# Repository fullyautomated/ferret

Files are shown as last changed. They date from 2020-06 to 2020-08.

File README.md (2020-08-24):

# Free-wheeling Ferret

USB-C Programmable Power Supply Source and Sink.

Back side optimized for JLCSMT, front for hand placing.
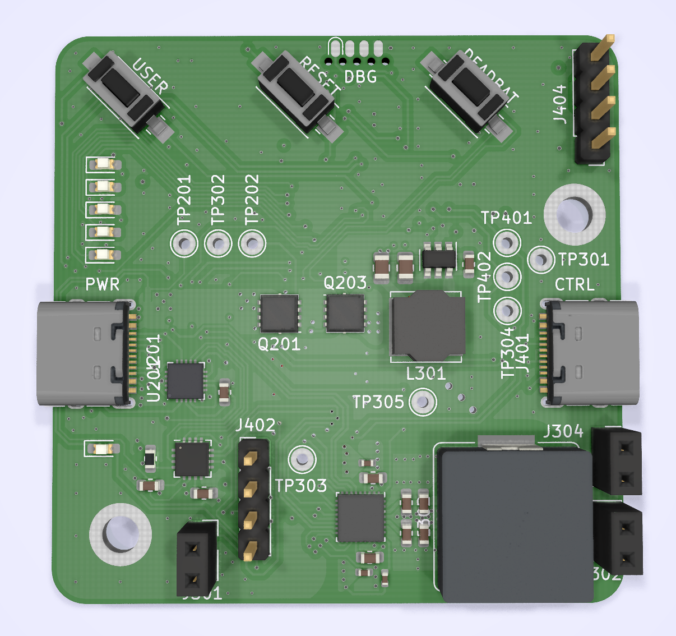
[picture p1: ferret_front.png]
Front

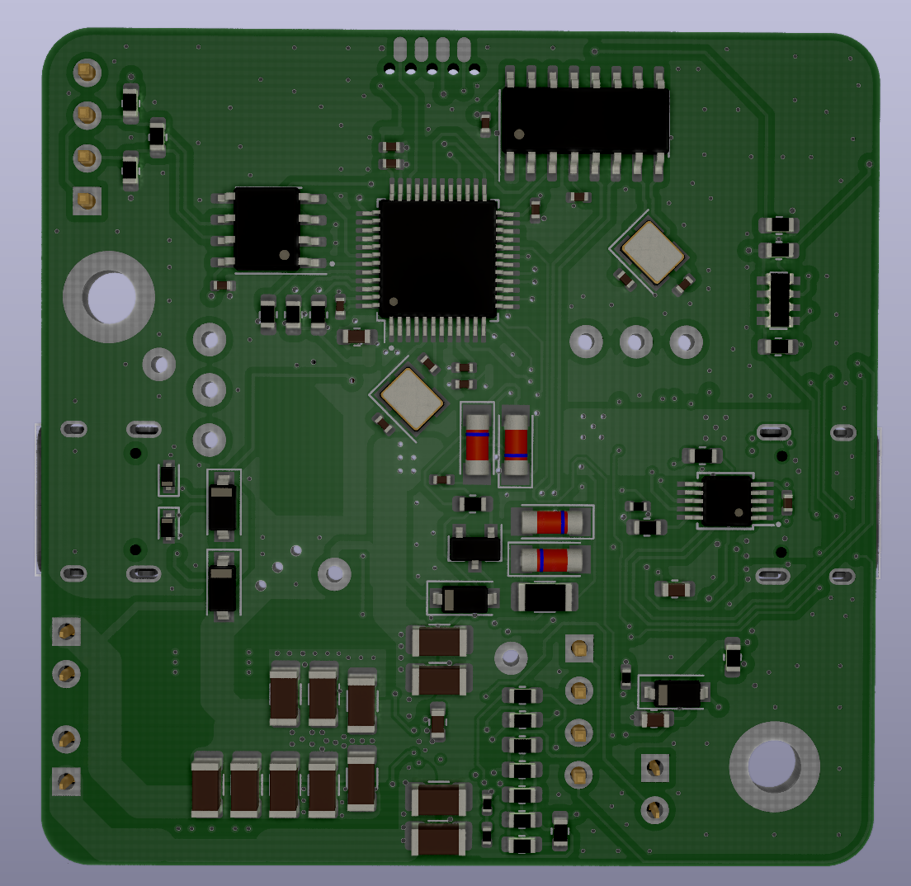
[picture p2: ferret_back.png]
Back


## Scattered Notes
Rough idea: Use the existing 10 boards to iron out firmware and get a good feel on the workings of USB-C PD. Then respin the boards, split the management functionality onto a separate board and make the Ferrets stackable.  

Ecosystem Idea:
 - Stackable Ferrets; you can have any\* amount of type C ports you can possibly need. Ferrets can have individual legacy electricity I/O, or can be tied to a single common bus. With the 
 - Configuration Board (top position only) you can monitor power flow and change port settings (source/sink, current and voltage) - this has a management interface (USB UART) and maybe Bluetooth/Wifi with an ESP32. Energy is stored in the
 - Battery Board; 4s BMS which can be attached to the bottom of a Ferret Stack. If you want to tie your Ferrets to a DC network with voltages usupported by the Ferret (so above 24V), you can just take an
 - Autobus; a 4-switch buck-boost converter with up to 60-V capability and hundreds of watts of power. This can easily interface with solar panels of larger size, 12-V lead-acid batteries, or 48-V grids. For cheaper, lower power connectivity you can use any additional stackable
 - Boost or Buck converter boards.

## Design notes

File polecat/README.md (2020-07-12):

# Pondering Polecat

USB-C PD PPS 8A supply breakout board. Just the initial schematic doodle for now.

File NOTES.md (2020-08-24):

# Notes about future revisions

## Alternative/interesting ICs

### ACT2861

The [ACT2861](https://www.qorvo.com/products/p/ACT2861) ([datasheet](https://www.qorvo.com/products/d/da006757)) is a 5S charger IC with OTG capabilities. Comparable with the TI chip, but not quite as good of a feature-set.

### ACT4752

The [ACT4752](https://www.qorvo.com/products/p/ACT4752) ([datasheet](https://www.qorvo.com/products/d/da007821)) is a cheaper alternative for source only applications but can be supplied with up to 40V and outputs up to 4A, with 256 step (15,625mA) current limit.

This would be perfect for output only boards, as it's also a lot cheaper (2.83EUR currently) and has integrated MOSFETs too.

### ISL95338

The [ISL95338](https://www.renesas.com/us/en/products/power-management/battery-management/multiple-cell-battery-chargers/device/ISL95338.html) ([datasheet](https://www.renesas.com/en-us/www/doc/datasheet/isl95338.pdf)) needs external MOSFETs and is *very* expensive. Not really interesting.

### LT8491

[LT8491](https://www.analog.com/en/products/lt8491.html) is just here for completeness sake. Up to 80V input, but ridicously expensive.

### TPS55288

The [TPS55288](https://www.ti.com/product/TPS55288) ([datasheet](https://www.ti.com/lit/ds/symlink/tps55288.pdf)) can do up to 16A out, but only up to 21.26V.
Small qty pricing is currently 4.4USD.

### BQ25713

The [BQ25713](https://www.ti.com/product/BQ25713) ([datasheet](https://www.ti.com/lit/ds/symlink/bq25713.pdf)) can only provide up to 20.8V but up to 8A and only costs 2.576USD for qty 1. Needs external MOSFETs though for better or worse.

See [polecat](polecat/) for schematic.

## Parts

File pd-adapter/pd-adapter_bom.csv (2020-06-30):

Designator | Comment | Footprint | Part Number
C3 C9 | 100nF | 0603 | C14663
C1 C5 C10 C11 C12 C13 C14 | 100nF/50V | 0603 | C14663
C2 | 10uF | 1206 | C13585
C6 | 10uF | 0603 | C19702
C4 C7 C15 | 10uF/10V | 0603 | C19702
C8 | 56pF/50V | 0603 | C39148
D5 | 24V | SOD-323 | C22619
D3 D4 | 3.3V | SOD-523 | C136161
D1 D2 D6 D7 | 5V | SOD-523 | C266462
D9 | Blue/2.8V | LED_0603 | C72041
D10 | Green/3.3V | LED_0603 | C72043
D8 | Red/2V | LED_0603 | C2286
D11 | White/2.9V | LED_0603 | C2290
D12 | Yellow/2.9V | LED_0603 | C72038
L1 | 10uH | 1210 | C86069
R13 | 10 | 0603 | C22859
R5 | 100k | 0603 | C25803
R8 | 10k | 0603 | C25804
R11 R15 | 130 | 0603 | C23185
R6 | 22k | 0603 | C31850
R1 R2 R3 R7 R9 R10 | 4.7k | 0603 | C23162
R12 R14 | 47 | 0603 | C23182
R4 | 49.9 | 0603 | C23185
U1 | FUSB302BMPX | MLP-14_EP_2.5x2.5x0.5P | C132291
U3 | STM32F072C8Tx | LQFP-48_7.0x7.0x0.5P | C80488
U2 | TPS54202DDC | SOT-23-6L | C191884

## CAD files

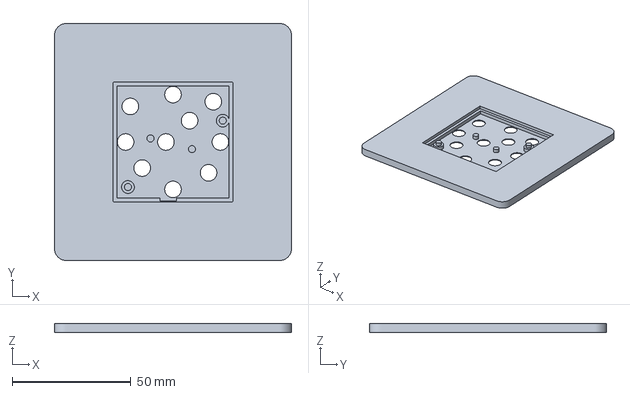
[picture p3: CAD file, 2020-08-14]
jig.3mf
100.0 x 100.0 x 4.00 mm

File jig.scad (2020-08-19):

totalThickness = 3.6;
pcbThickness = 1.65;

holeD = 3.0;
holeShrouD = 5.4;

gap = 0.12;
pcb = [50,50,pcbThickness];

pcbShroud = 1.4;

base = [110, 130, 0.4];

stencilOffset = [0,20,0];
cornerRadius = 5;

holes = [[6,6], [46, 34]];
supportPegs = [[15.5, 26.5], [33, 22]];
supportPegD = 3;

module supports() {
    supportPegH = base.z + totalThickness;
    supportH = supportPegH - pcbThickness;
    
    translate([pcb.x/-2, pcb.y/-2, 0]) {
        for(v=holes)
            translate(v) {
                cylinder(d=holeD, h=supportPegH);
                cylinder(d=holeShrouD, h=supportH);
            }
            
        for(v=supportPegs)
            translate(v)
                cylinder(d=supportPegD, h=supportH); 
        }
}

function getCorners(dim, rr) = (
        [[rr,rr],
        [dim.x - rr, rr],
        [dim.x - rr, dim.y - rr],
        [rr, dim.y - rr]]);

module roundedCube(dim, rr, center=false) {
    translate(center?(-0.5*dim):[0,0,0])
        linear_extrude(dim.z)
            hull()
                for(vector = getCorners(dim, rr))
                    translate(vector)
                        circle(rr);
}

module roundedSquare(dim, rr, center=false) {
        translate(center?(-0.5*[dim.x,dim.y]):[0,0,0])
            hull()
                for(vector = getCorners(dim, rr))
                    translate(vector)
                        circle(rr);
}

module main() {
    totalZ = base.z + totalThickness;
    insides = pcb - pcbShroud*[2,2,0] + [0,0,totalThickness];
    difference() {
        union() {
            // main part +
            translate(stencilOffset)
                linear_extrude(totalZ)
                    roundedSquare([base.x, base.y], cornerRadius, center=true);
        }
        union() {
            // pcb -
            translate([0,0,totalZ-pcb.z])
                linear_extrude(totalZ)
                    offset(r=2*gap)
                        square([pcb.x, pcb.y], center=true);
            
            // clearance for underside 
            // components -
            translate([0,0,base.z])
                linear_extrude(insides.z)
                    square([insides.x, insides.y], center=true);
            
            // additional clearance -
            translate([pcb.x/-2, pcb.y/-2,base.z])
                translate([27, 1.2])
                    linear_extrude(totalZ)
                        square([9,2], center=true);
            
            // eject holes -
            eh = [[25,5], [25,45], [5,25], [45,25], [22, 25], [40, 12], [7, 40], [42, 42], [32,34], [12,14]];
            translate([pcb.x/-2, pcb.y/-2, -1])
            for(v=eh)
                translate(v)
                    cylinder(d=7, h=base.z+2);
        }
    }
    supports();
}

$fn = 64;
main();

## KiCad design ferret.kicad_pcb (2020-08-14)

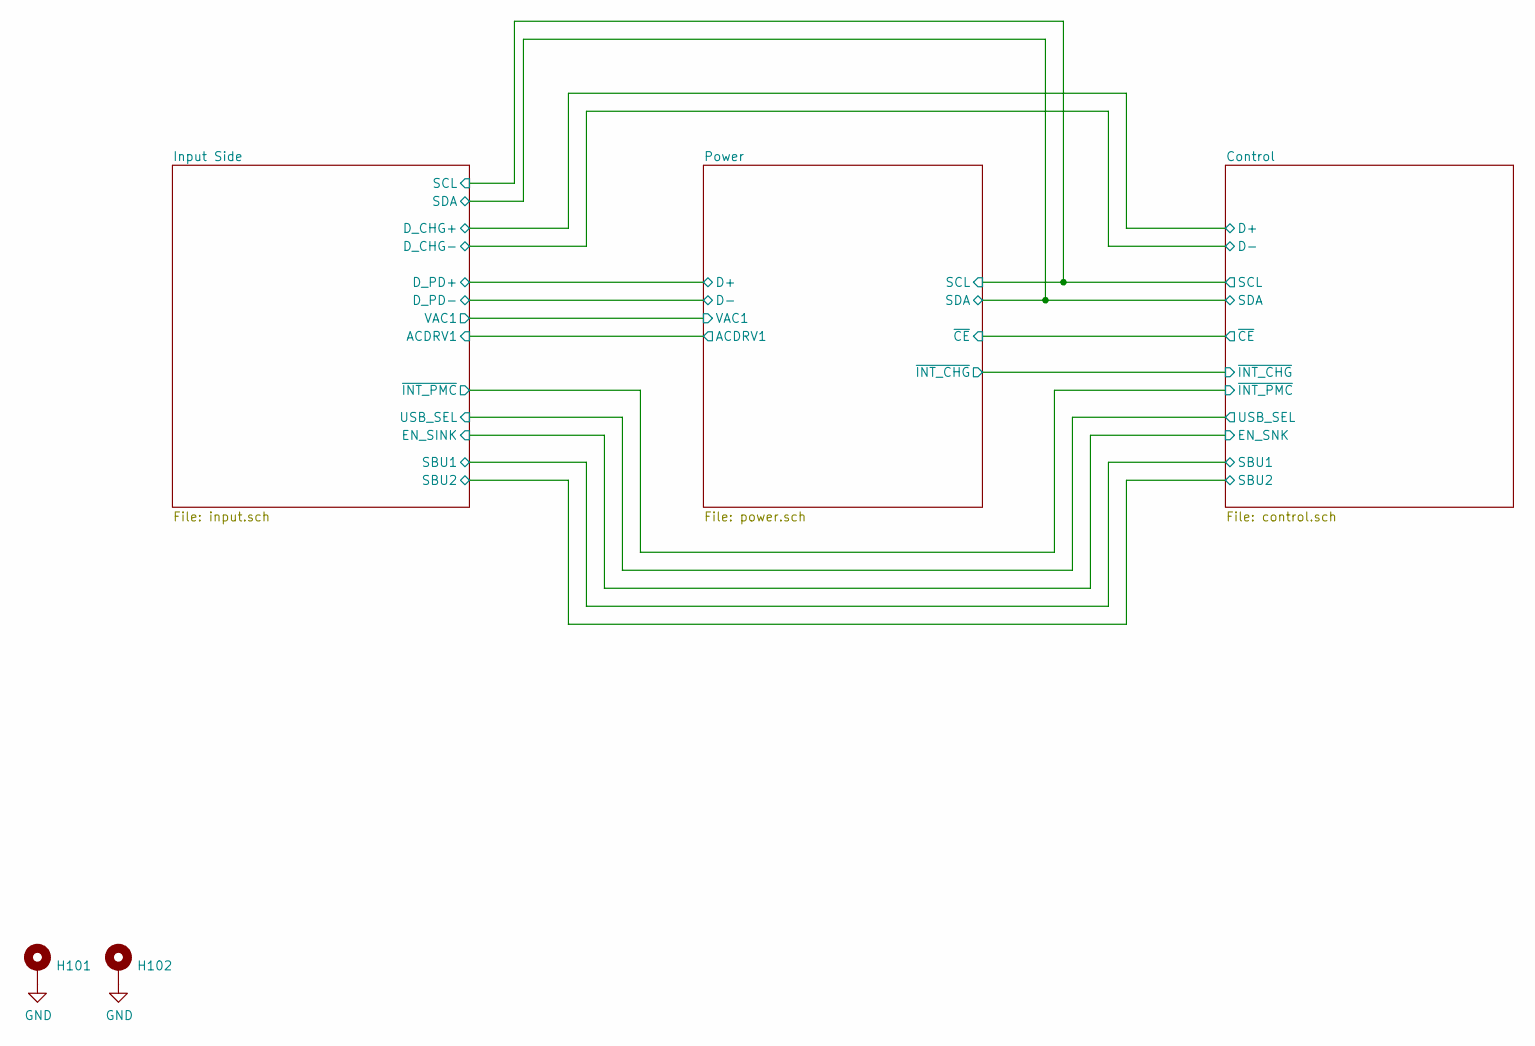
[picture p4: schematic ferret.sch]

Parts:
H101, H102: MountingHole_Pad; MountingHole_3.2mm_M3_ISO14580_Pad; MPN DNP

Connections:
GND: H101.1, H102.1; also elsewhere on the board

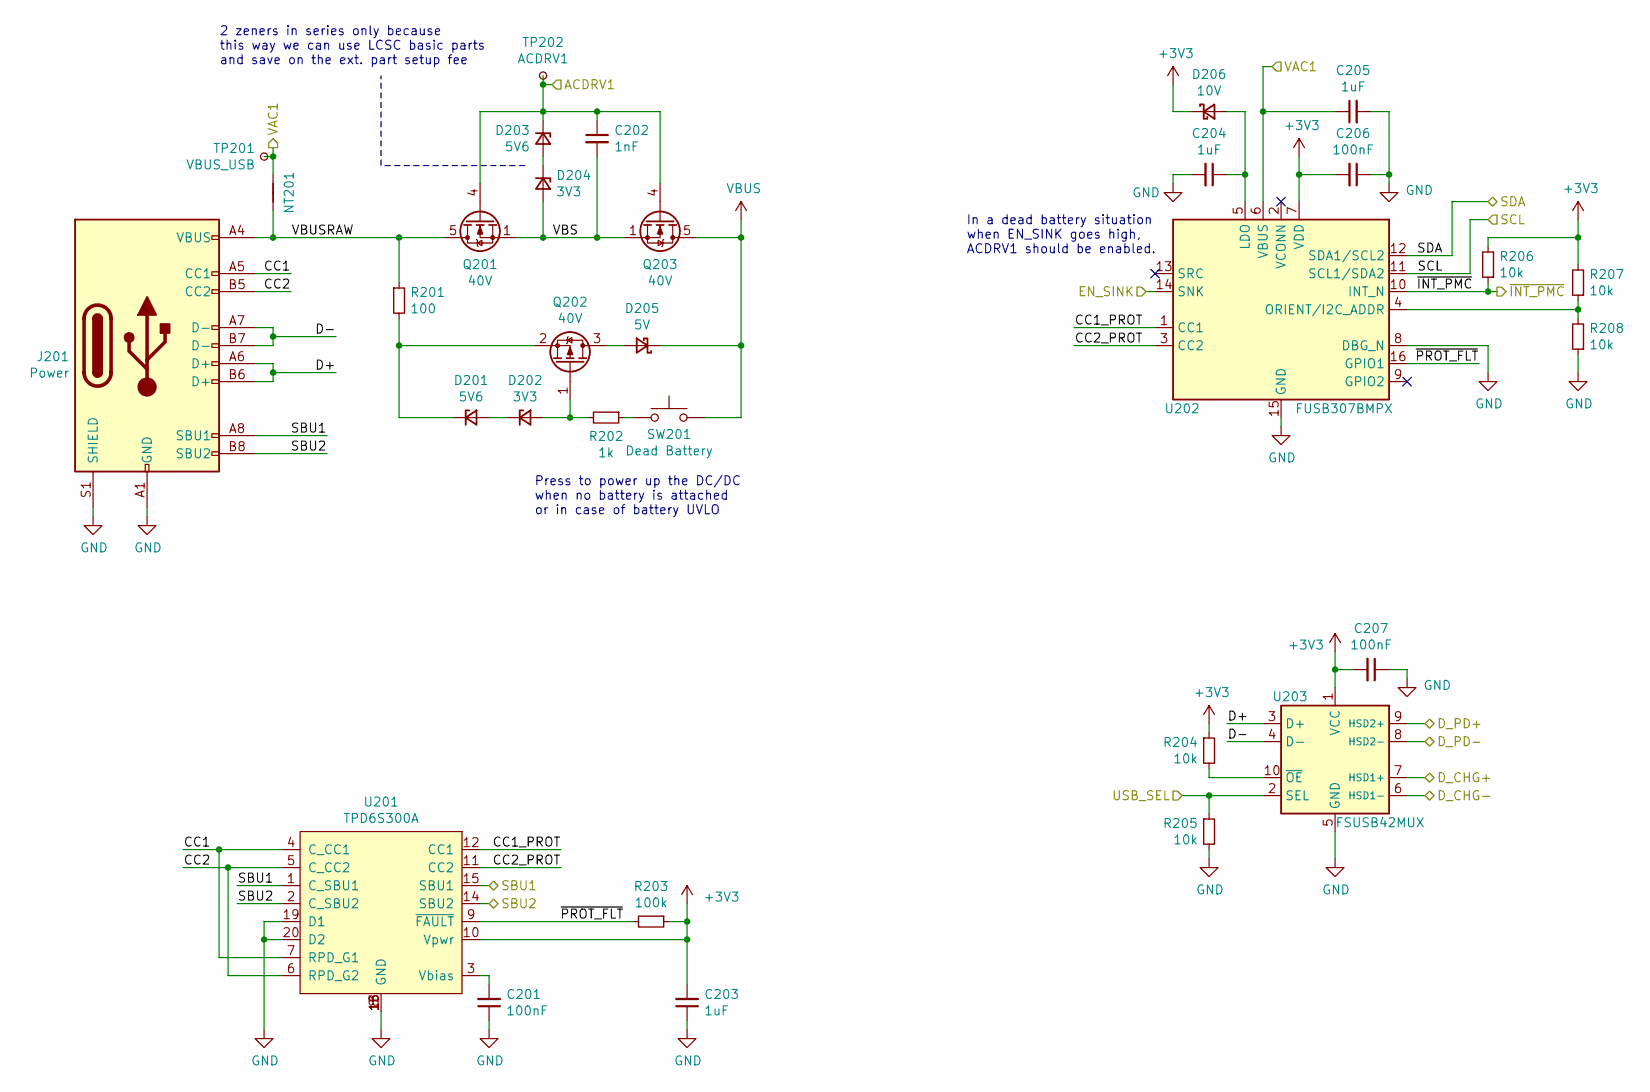
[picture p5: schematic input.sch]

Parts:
C201, C206: 100nF; C_0603_1608Metric; MPN CC0603KRX7R9BB104; JLC 0603
C202: 1nF; C_0402_1005Metric; JLC 0402
C203: 1uF; C_0603_1608Metric; MPN CL10A105KB8NNNC; LCSC C15849
C204: 1uF; C_0603_1608Metric
C205: 1uF; C_0603_1608Metric; LCSC C15849
C207: 100nF; C_0402_1005Metric; JLC 0402
D201, D203: 5V6; D_MiniMELF; MPN ZMM5V6; JLC LL-34
D202, D204: 3V3; D_MiniMELF; MPN ZMM3V3; JLC LL-34
D205: 5V; D_SOD-123; MPN B5819W; JLC SOD-123
D206: 10V; D_SOD-123; MPN B5819W; LCSC C8598
J201: Power; USB_C_Receptacle_XKB_U262-16XN-4BVC11
NT201: UwU; NetTie-2_SMD_Pad0.5mm; MPN DNP
Q201, Q203: 40V; Vishay_PowerPAK_1212-8_Single; MPN SiSS10ADN
Q202: 40V; SOT-23; MPN AO3401; JLC SOT-23-3L
R201: 100; R_1206_3216Metric; MPN 1206W4F1000T5E; JLC 1206
R202: 1k; R_0603_1608Metric; MPN 0603WAF1001T5E; JLC 0603
R203: 100k; R_0402_1005Metric; JLC 0402
R204, R205: 10k; R_0603_1608Metric; JLC 0603
R206: 10k; R_0402_1005Metric; JLC 0402
R207, R208: 10k; R_0603_1608Metric; MPN DNP; JLC 0603
SW201: Dead Battery; SW_SPST_PTS636_G
TP201: VBUS_USB; TestPoint_THTPad_D2.0mm_Drill1.0mm
TP202: ACDRV1; TestPoint_THTPad_D2.0mm_Drill1.0mm
U201: TPD6S300A; QFN-20-1EP_3x3mm_P0.4mm_EP1.65x1.65mm; MPN TPD6S300ARUKR
U202: FUSB307BMPX; WQFN-16-1EP_3x3mm_P0.5mm_EP1.75x1.75mm
U203: FSUSB42MUX; MSOP-10_3x3mm_P0.5mm; MPN FSUSB42MUX; JLC MSOP-10_3.0x3.0x0.5P

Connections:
+3V3: C203.2, C206.2, C207.2, D206.1 (K), R203.1, R204.1, R206.2, R207.2, U201.10 (Vpwr), U202.7 (VDD), U203.1 (VCC); also elsewhere on the board
/Control/D+: U203.7 (HSD1+); also elsewhere on the board
/Control/D-: U203.6 (HSD1-); also elsewhere on the board
/Control/SBU1: J201.A8 (SBU1), U201.1 (C_SBU1), U201.15 (SBU1); also elsewhere on the board
/Control/SBU2: J201.B8 (SBU2), U201.2 (C_SBU2), U201.14 (SBU2); also elsewhere on the board
/Control/SCL: U202.11 (SCL1/SDA2); also elsewhere on the board
/Control/SDA: U202.12 (SDA1/SCL2); also elsewhere on the board
/Control/USB_SEL: R205.1, U203.2 (SEL); also elsewhere on the board
/Control/~INT_PMC: R206.1, U202.10 (INT_N); also elsewhere on the board
/Input Side/ACDRV1: C202.1, D203.1 (K), Q201.4 (G), Q203.4 (G), TP202.1; also elsewhere on the board
/Input Side/CC1: J201.A5 (CC1), U201.4 (C_CC1), U201.7 (RPD_G1)
/Input Side/CC1_PROT: U201.12 (CC1), U202.1 (CC1)
/Input Side/CC2: J201.B5 (CC2), U201.5 (C_CC2), U201.6 (RPD_G2)
/Input Side/CC2_PROT: U201.11 (CC2), U202.3 (CC2)
/Input Side/D+: J201.A6 (D+), J201.B6 (D+), U203.3 (D+)
/Input Side/D-: J201.A7 (D-), J201.B7 (D-), U203.4 (D-)
/Input Side/EN_SINK: U202.14 (SNK); also elsewhere on the board
/Input Side/VAC1: C205.1, NT201.1, TP201.1, U202.6 (VBUS); also elsewhere on the board
/Input Side/VBS: C202.2, D204.2 (A), Q201.1 (S), Q201.2 (S), Q201.3 (S), Q203.1 (S), Q203.2 (S), Q203.3 (S)
/Input Side/VBUSRAW: J201.A4 (VBUS), J201.A9 (VBUS), J201.B4 (VBUS), J201.B9 (VBUS), NT201.2, Q201.5 (D), R201.1
/Input Side/~PROT_FLT: R203.2, U201.9 (~FAULT), U202.16 (GPIO1)
/Power/D+: U203.9 (HSD2+); also elsewhere on the board
/Power/D-: U203.8 (HSD2-); also elsewhere on the board
GND: C201.1, C203.1, C204.2, C205.2, C206.1, C207.1, J201.A1 (GND), J201.A12 (GND), J201.B1 (GND), J201.B12 (GND), J201.S1 (SHIELD), R205.2, R208.1, U201.8 (GND), U201.13 (GND), U201.16 (NC), U201.17 (NC), U201.18 (GND), U201.19 (D1), U201.20 (D2), U201.21 (Thermal_Pad), U202.8 (DBG_N), U202.15 (GND), U202.17 (GND), U203.5 (GND); also elsewhere on the board
unnamed: C201.2, U201.3 (Vbias)
unnamed: C204.1, D206.2 (A), U202.5 (LDO)
unnamed: D201.1 (K), Q202.2 (S), R201.2
unnamed: D201.2 (A), D202.1 (K)
unnamed: D202.2 (A), Q202.1 (G), R202.2
unnamed: D203.2 (A), D204.1 (K)
unnamed: D205.2 (A), Q202.3 (D)
unnamed: R202.1, SW201.1
unnamed: R204.2, U203.10 (~OE)
unnamed: R207.1, R208.2, U202.4 (ORIENT/I2C_ADDR)
VBUS: D205.1 (K), Q203.5 (D), SW201.2; also elsewhere on the board

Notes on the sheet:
In a dead battery situation when EN_SINK goes high, ACDRV1 should be enabled.
Press to power up the DC/DC when no battery is attached or in case of battery UVLO
2 zeners in series only because this way we can use LCSC basic parts and save on the ext. part setup fee

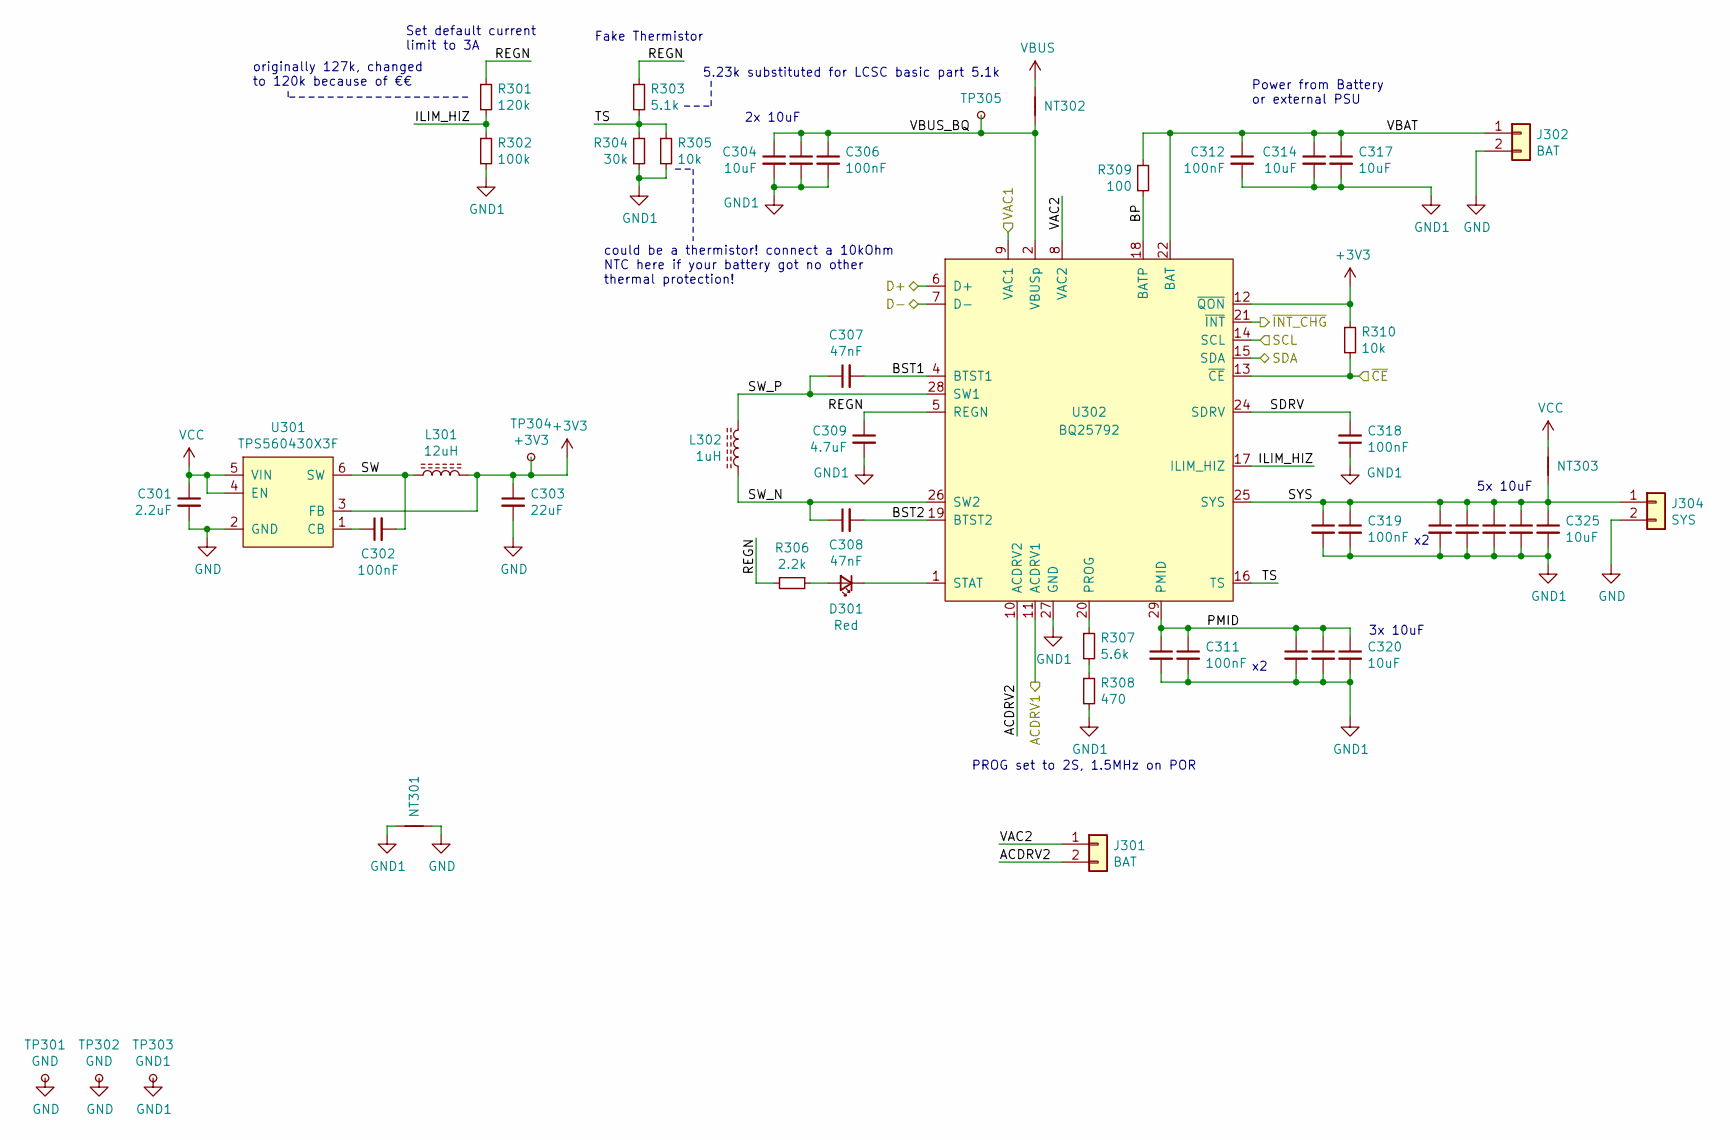
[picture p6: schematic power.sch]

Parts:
C301: 2.2uF; C_0805_2012Metric; MPN 0805F225M500NT; JLC 0805
C302: 100nF; C_0603_1608Metric; MPN CC0603KRX7R9BB104; JLC 0603
C303: 22uF; C_0805_2012Metric; MPN CL21A226MAQNNNE; JLC 0805
C304, C305, C313, C314, C316, C317, C320, C321, C322, C323, C324, C325: 10uF; C_1206_3216Metric; MPN CL31A106KBHNNNE; JLC 1206
C306, C312: 100nF; C_0402_1005Metric; JLC 0402
C307, C308: 47nF; C_0603_1608Metric
C309: 4.7uF; C_0603_1608Metric; MPN CL10A475KO8NNNC; JLC 0603
C310, C311, C315, C319: 100nF; C_0603_1608Metric
C318: 100nF; C_0402_1005Metric
D301: Red; LED_0603_1608Metric_Castellated
J301, J302: BAT; PinSocket_1x02_P2.54mm_Vertical
J304: SYS; PinSocket_1x02_P2.54mm_Vertical
L301: 12uH; L_Bourns_SRN6045TA; MPN SRN6045TA-120M
L302: 1uH; L_Bourns_SRP1245A; MPN SRP1265A-1R0M
NT301: chonk; NetTie-2_SMD_Pad2.0mm
NT302: chonk_vbus; NetTie-2_SMD_Pad2.0mm
NT303: chonk; NetTie-2_SMD_Pad0.5mm
R301: 120k; R_0603_1608Metric; JLC 0603
R302: 100k; R_0603_1608Metric; JLC 0603
R303: 5.1k; R_0603_1608Metric; JLC 0603
R304: 30k; R_0603_1608Metric; LCSC C22984
R305, R310: 10k; R_0603_1608Metric; JLC 0603
R306: 2.2k; R_0603_1608Metric; MPN 0603WAF2201T5E; JLC 0603
R307: 5.6k; R_0402_1005Metric; JLC 0603
R308: 470; R_0402_1005Metric; LCSC C25117
R309: 100; R_0603_1608Metric; MPN 0603WAF1000T5E; JLC 0603
TP301, TP302: GND; TestPoint_THTPad_D2.0mm_Drill1.0mm
TP303: GND1; TestPoint_THTPad_D2.0mm_Drill1.0mm
TP304: +3V3; TestPoint_THTPad_D2.0mm_Drill1.0mm
TP305: VBUS_BQ; TestPoint_THTPad_D2.0mm_Drill1.0mm
U301: TPS560430X3F; SOT-23-6; JLC SOT-23-6L
U302: BQ25792; Texas_VQFN-HR_RQM_4x4mm_P0.40-0.45mm

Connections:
+3V3: C303.1, L301.2, R310.1, TP304.1, U301.3 (FB), U302.12 (~QON); also elsewhere on the board
/Control/SCL: U302.14 (SCL); also elsewhere on the board
/Control/SDA: U302.15 (SDA); also elsewhere on the board
/Control/~CE: R310.2, U302.13 (~CE); also elsewhere on the board
/Control/~INT_CHG: U302.21 (~INT); also elsewhere on the board
/Input Side/ACDRV1: U302.11 (ACDRV1); also elsewhere on the board
/Input Side/VAC1: U302.9 (VAC1); also elsewhere on the board
/Power/ACDRV2: J301.2, U302.10 (ACDRV2)
/Power/BP: R309.2, U302.18 (BATP)
/Power/BST1: C307.2, U302.4 (BTST1)
/Power/BST2: C308.2, U302.19 (BTST2)
/Power/D+: U302.6 (D+); also elsewhere on the board
/Power/D-: U302.7 (D-); also elsewhere on the board
/Power/ILIM_HIZ: R301.2, R302.1, U302.17 (ILIM_HIZ)
/Power/PMID: C310.1, C311.1, C313.1, C316.1, C320.1, U302.29 (PMID)
/Power/REGN: C309.1, R301.1, R303.1, R306.2, U302.5 (REGN)
/Power/SDRV: C318.2, U302.24 (SDRV)
/Power/SW: C302.2, L301.1, U301.6 (SW)
/Power/SW_N: C308.1, L302.1, U302.26 (SW2)
/Power/SW_P: C307.1, L302.2, U302.28 (SW1)
/Power/SYS: C315.1, C319.1, C321.1, C322.1, C323.1, C324.1, C325.1, J304.1, NT303.2, U302.25 (SYS)
/Power/TS: R303.2, R304.1, R305.1, U302.16 (TS)
/Power/VAC2: J301.1, U302.8 (VAC2)
/Power/VBAT: C312.1, C314.1, C317.1, J302.1, R309.1, U302.22 (BAT), U302.23 (BAT)
GND: C301.2, C303.2, J302.2, J304.2, NT301.2, TP301.1, TP302.1, U301.2 (GND); also elsewhere on the board
GND1: C304.2, C305.2, C306.2, C309.2, C310.2, C311.2, C312.2, C313.2, C314.2, C315.2, C316.2, C317.2, C318.1, C319.2, C320.2, C321.2, C322.2, C323.2, C324.2, C325.2, NT301.1, R302.2, R304.2, R305.2, R308.2, TP303.1, U302.27 (GND)
unnamed: C302.1, U301.1 (CB)
unnamed: D301.1 (K), U302.1 (STAT)
unnamed: D301.2 (A), R306.1
unnamed: R307.1, U302.20 (PROG)
unnamed: R307.2, R308.1
VBUS: NT302.1; also elsewhere on the board
VBUSp: C304.1, C305.1, C306.1, NT302.2, TP305.1, U302.2 (VBUSp), U302.3 (VBUSp)
VCC: C301.1, NT303.1, U301.4 (EN), U301.5 (VIN); also elsewhere on the board

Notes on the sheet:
3x 10uF
PROG set to 2S, 1.5MHz on POR
Set default current limit to 3A
5x 10uF
Fake Thermistor
2x 10uF
Power from Battery or external PSU
5.23k substituted for LCSC basic part 5.1k
could be a thermistor! connect a 10kOhm NTC here if your battery got no other thermal protection!
originally 127k, changed to 120k because of €€

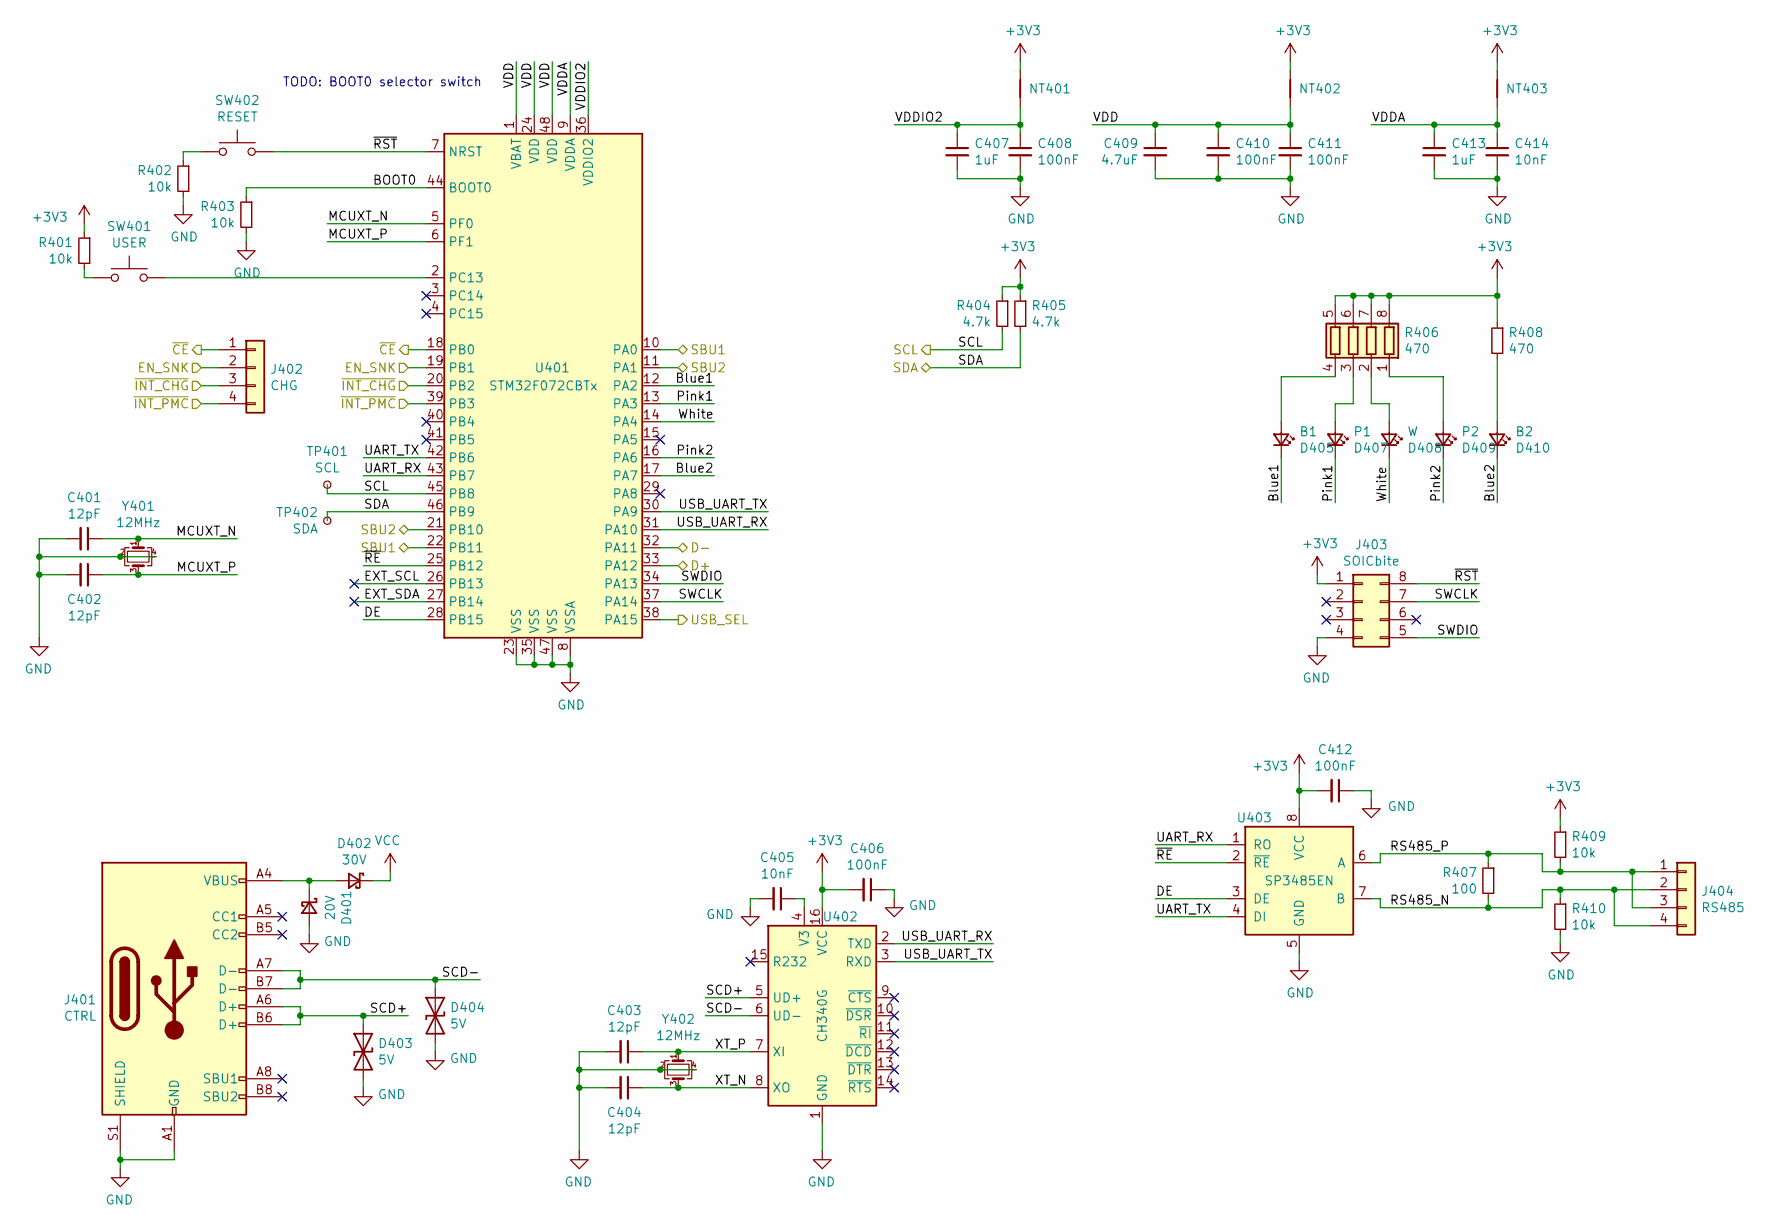
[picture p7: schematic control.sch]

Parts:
C401, C402, C403, C404: 12pF; C_0402_1005Metric; MPN 0402CG120J500NT; LCSC C1547
C405, C414: 10nF; C_0402_1005Metric; LCSC C15195
C406, C408, C410, C411, C412: 100nF; C_0402_1005Metric; MPN CL05B104KO5NNNC; JLC 0402
C407, C413: 1uF; C_0402_1005Metric; LCSC C52923
C409: 4.7uF; C_0603_1608Metric; MPN CL10A475KO8NNNC; JLC 0603
D401: 20V; D_SOD-123; MPN B5819W; LCSC C8598
D402: 30V; D_SOD-123; MPN B5819W; LCSC C8598
D403, D404: 5V; D_SOD-523; MPN ESD5Z3.3T1G; JLC SOD-523
D405: B1; LED_0603_1608Metric_Castellated; MPN OSB60603C1E
D407: P1; LED_0603_1608Metric_Castellated; MPN OSK40603C1E
D408: W; LED_0603_1608Metric_Castellated; MPN OSW50603C1E
D409: P2; LED_0603_1608Metric_Castellated; MPN OSK40603C1E
D410: B2; LED_0603_1608Metric_Castellated; MPN OSB60603C1E
J401: CTRL; USB_C_Receptacle_XKB_U262-16XN-4BVC11
J402: CHG; PinHeader_1x04_P2.54mm_Vertical
J403: SOICbite; SOIC_clipProgSmall
J404: RS485; PinHeader_1x04_P2.54mm_Vertical
NT401: VDDIO2; NetTie-2_SMD_Pad0.5mm; MPN DNP
NT402: VDD; NetTie-2_SMD_Pad0.5mm; MPN DNP
NT403: VDDA; NetTie-2_SMD_Pad0.5mm; MPN DNP
R401, R402, R403, R409, R410: 10k; R_0603_1608Metric; JLC 0603
R404, R405: 4.7k; R_0603_1608Metric; JLC 0603
R406: 470; R_Array_Convex_4x0603; MPN 4D03WGJ0471T5E; JLC 0603_x4
R407: 100; R_0603_1608Metric; MPN 0603WAF1000T5E; JLC 0603
R408: 470; R_0603_1608Metric; JLC 0603
SW401: USER; SW_SPST_PTS636_G
SW402: RESET; SW_SPST_PTS636_G
TP401: SCL; TestPoint_THTPad_D2.0mm_Drill1.0mm
TP402: SDA; TestPoint_THTPad_D2.0mm_Drill1.0mm
U401: STM32F072CBTx; LQFP-48_7x7mm_P0.5mm; MPN STM32F072C8T6; JLC LQFP-48_7.0x7.0x0.5P
U402: CH340G; SOIC-16_3.9x9.9mm_P1.27mm; MPN CH340G; JLC SOIC-16_3.9x9.9x1.27P
U403: SP3485EN; SOIC-8_3.9x4.9mm_P1.27mm; MPN SP3485EN-L/TR; JLC SOIC-8_3.9x4.9x1.27P
Y401, Y402: 12MHz; Crystal_SMD_3225-4Pin_3.2x2.5mm; MPN X322512MSB4SI; JLC SMD-3225_4P

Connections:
+3V3: C406.2, C412.2, J403.1, NT401.1, NT402.1, NT403.1, R401.1, R404.1, R405.1, R406.5 (R4.2), R406.6 (R3.2), R406.7 (R2.2), R406.8 (R1.2), R408.1, R409.1, U402.16 (VCC), U403.8 (VCC); also elsewhere on the board
/Control/BOOT0: R403.1, U401.44 (BOOT0)
/Control/Blue1: D405.1 (K), U401.12 (PA2)
/Control/Blue2: D410.1 (K), U401.17 (PA7)
/Control/D+: U401.33 (PA12); also elsewhere on the board
/Control/D-: U401.32 (PA11); also elsewhere on the board
/Control/DE: U401.28 (PB15), U403.3 (DE)
/Control/EXT_SCL: U401.26 (PB13)
/Control/EXT_SDA: U401.27 (PB14)
/Control/MCUXT_N: C401.1, U401.5 (PF0), Y401.1
/Control/MCUXT_P: C402.1, U401.6 (PF1), Y401.3
/Control/Pink1: D407.1 (K), U401.13 (PA3)
/Control/Pink2: D409.1 (K), U401.16 (PA6)
/Control/RS485_N: J404.2, J404.4, R407.2, R410.1, U403.7 (B)
/Control/RS485_P: J404.1, J404.3, R407.1, R409.2, U403.6 (A)
/Control/SBU1: U401.10 (PA0), U401.22 (PB11); also elsewhere on the board
/Control/SBU2: U401.11 (PA1), U401.21 (PB10); also elsewhere on the board
/Control/SCD+: D403.1 (A1), J401.A6 (D+), J401.B6 (D+), U402.5 (UD+)
/Control/SCD-: D404.1 (A1), J401.A7 (D-), J401.B7 (D-), U402.6 (UD-)
/Control/SCL: R404.2, TP401.1, U401.45 (PB8); also elsewhere on the board
/Control/SDA: R405.2, TP402.1, U401.46 (PB9); also elsewhere on the board
/Control/SWCLK: J403.7, U401.37 (PA14)
/Control/SWDIO: J403.5, U401.34 (PA13)
/Control/UART_RX: U401.43 (PB7), U403.1 (RO)
/Control/UART_TX: U401.42 (PB6), U403.4 (DI)
/Control/USB_SEL: U401.38 (PA15); also elsewhere on the board
/Control/USB_UART_RX: U401.31 (PA10), U402.2 (TXD)
/Control/USB_UART_TX: U401.30 (PA9), U402.3 (RXD)
/Control/VDD: C409.1, C410.1, C411.1, NT402.2, U401.1 (VBAT), U401.24 (VDD), U401.48 (VDD)
/Control/VDDA: C413.1, C414.1, NT403.2, U401.9 (VDDA)
/Control/VDDIO2: C407.1, C408.1, NT401.2, U401.36 (VDDIO2)
/Control/White: D408.1 (K), U401.14 (PA4)
/Control/XT_N: C404.1, U402.8 (XO), Y402.3
/Control/XT_P: C403.1, U402.7 (XI), Y402.1
/Control/~CE: J402.1, U401.18 (PB0); also elsewhere on the board
/Control/~INT_CHG: J402.3, U401.20 (PB2); also elsewhere on the board
/Control/~INT_PMC: J402.4, U401.39 (PB3); also elsewhere on the board
/Control/~RE: U401.25 (PB12), U403.2 (~RE~)
/Control/~RST: J403.8, SW402.2, U401.7 (NRST)
/Input Side/EN_SINK: J402.2, U401.19 (PB1); also elsewhere on the board
GND: C401.2, C402.2, C403.2, C404.2, C405.2, C406.1, C407.2, C408.2, C409.2, C410.2, C411.2, C412.1, C413.2, C414.2, D401.2 (A), D403.2 (A2), D404.2 (A2), J401.A1 (GND), J401.A12 (GND), J401.B1 (GND), J401.B12 (GND), J401.S1 (SHIELD), J403.4, R402.2, R403.2, R410.2, U401.8 (VSSA), U401.23 (VSS), U401.35 (VSS), U401.47 (VSS), U402.1 (GND), U403.5 (GND), Y401.2, Y401.4, Y402.2, Y402.4; also elsewhere on the board
unnamed: C405.1, U402.4 (V3)
unnamed: D401.1 (K), D402.2 (A), J401.A4 (VBUS), J401.A9 (VBUS), J401.B4 (VBUS), J401.B9 (VBUS)
unnamed: D405.2 (A), R406.4 (R4.1)
unnamed: D407.2 (A), R406.3 (R3.1)
unnamed: D408.2 (A), R406.2 (R2.1)
unnamed: D409.2 (A), R406.1 (R1.1)
unnamed: D410.2 (A), R408.2
unnamed: R401.2, SW401.1
unnamed: R402.1, SW402.1
unnamed: SW401.2, U401.2 (PC13)
VCC: D402.1 (K); also elsewhere on the board

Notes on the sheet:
TODO: BOOT0 selector switch

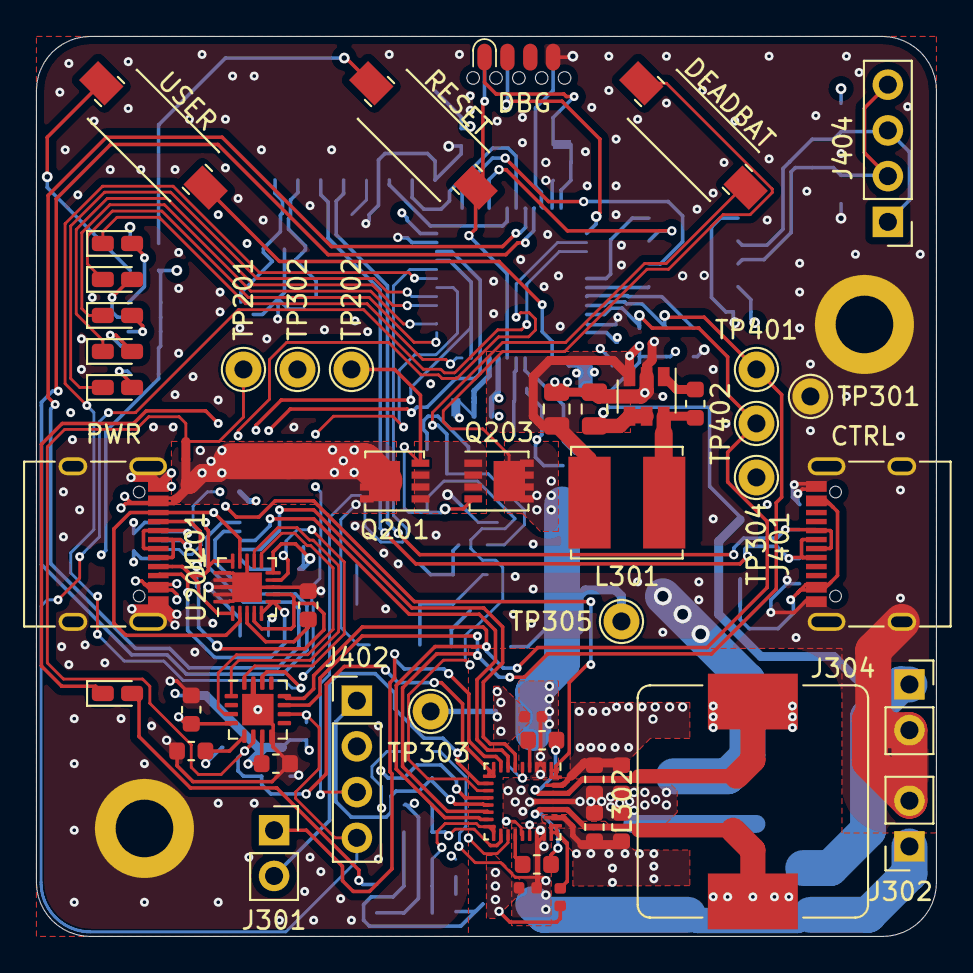
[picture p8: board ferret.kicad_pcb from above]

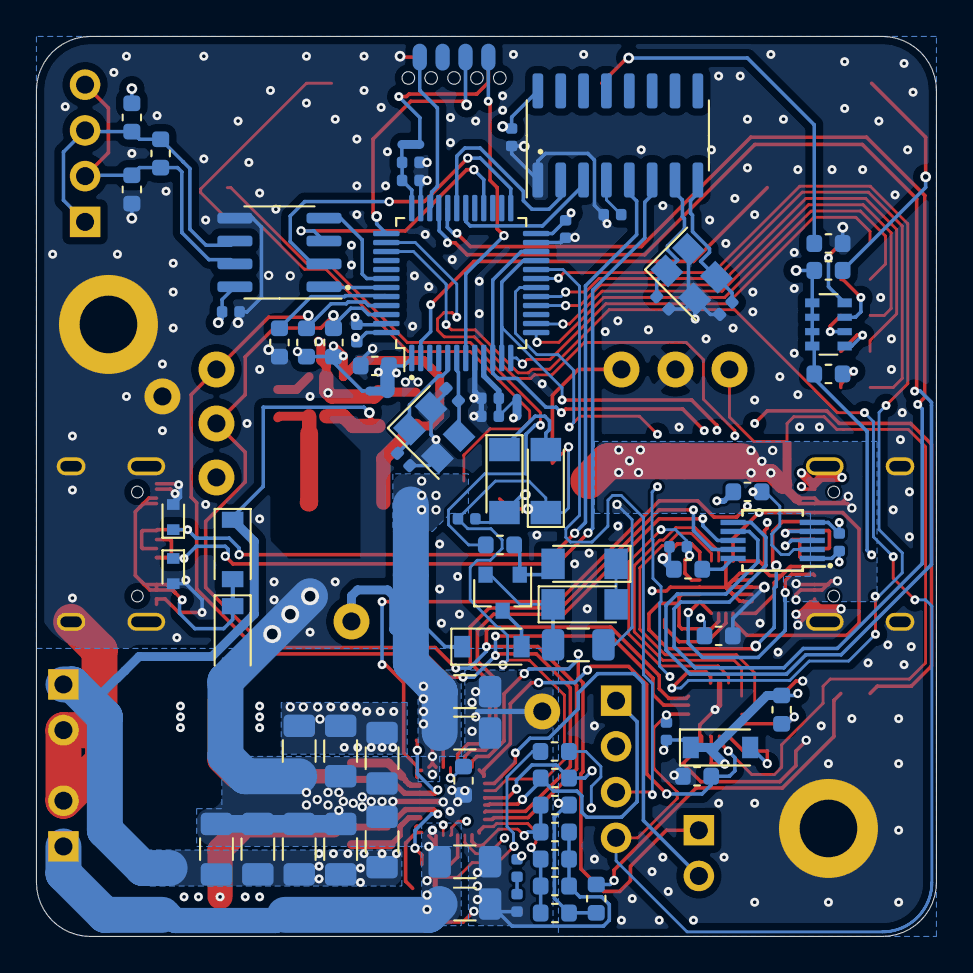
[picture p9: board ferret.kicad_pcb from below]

Board: 4 copper layers, 50.0 x 50.0 mm, 134 parts (81 on the bottom side), 96 nets.

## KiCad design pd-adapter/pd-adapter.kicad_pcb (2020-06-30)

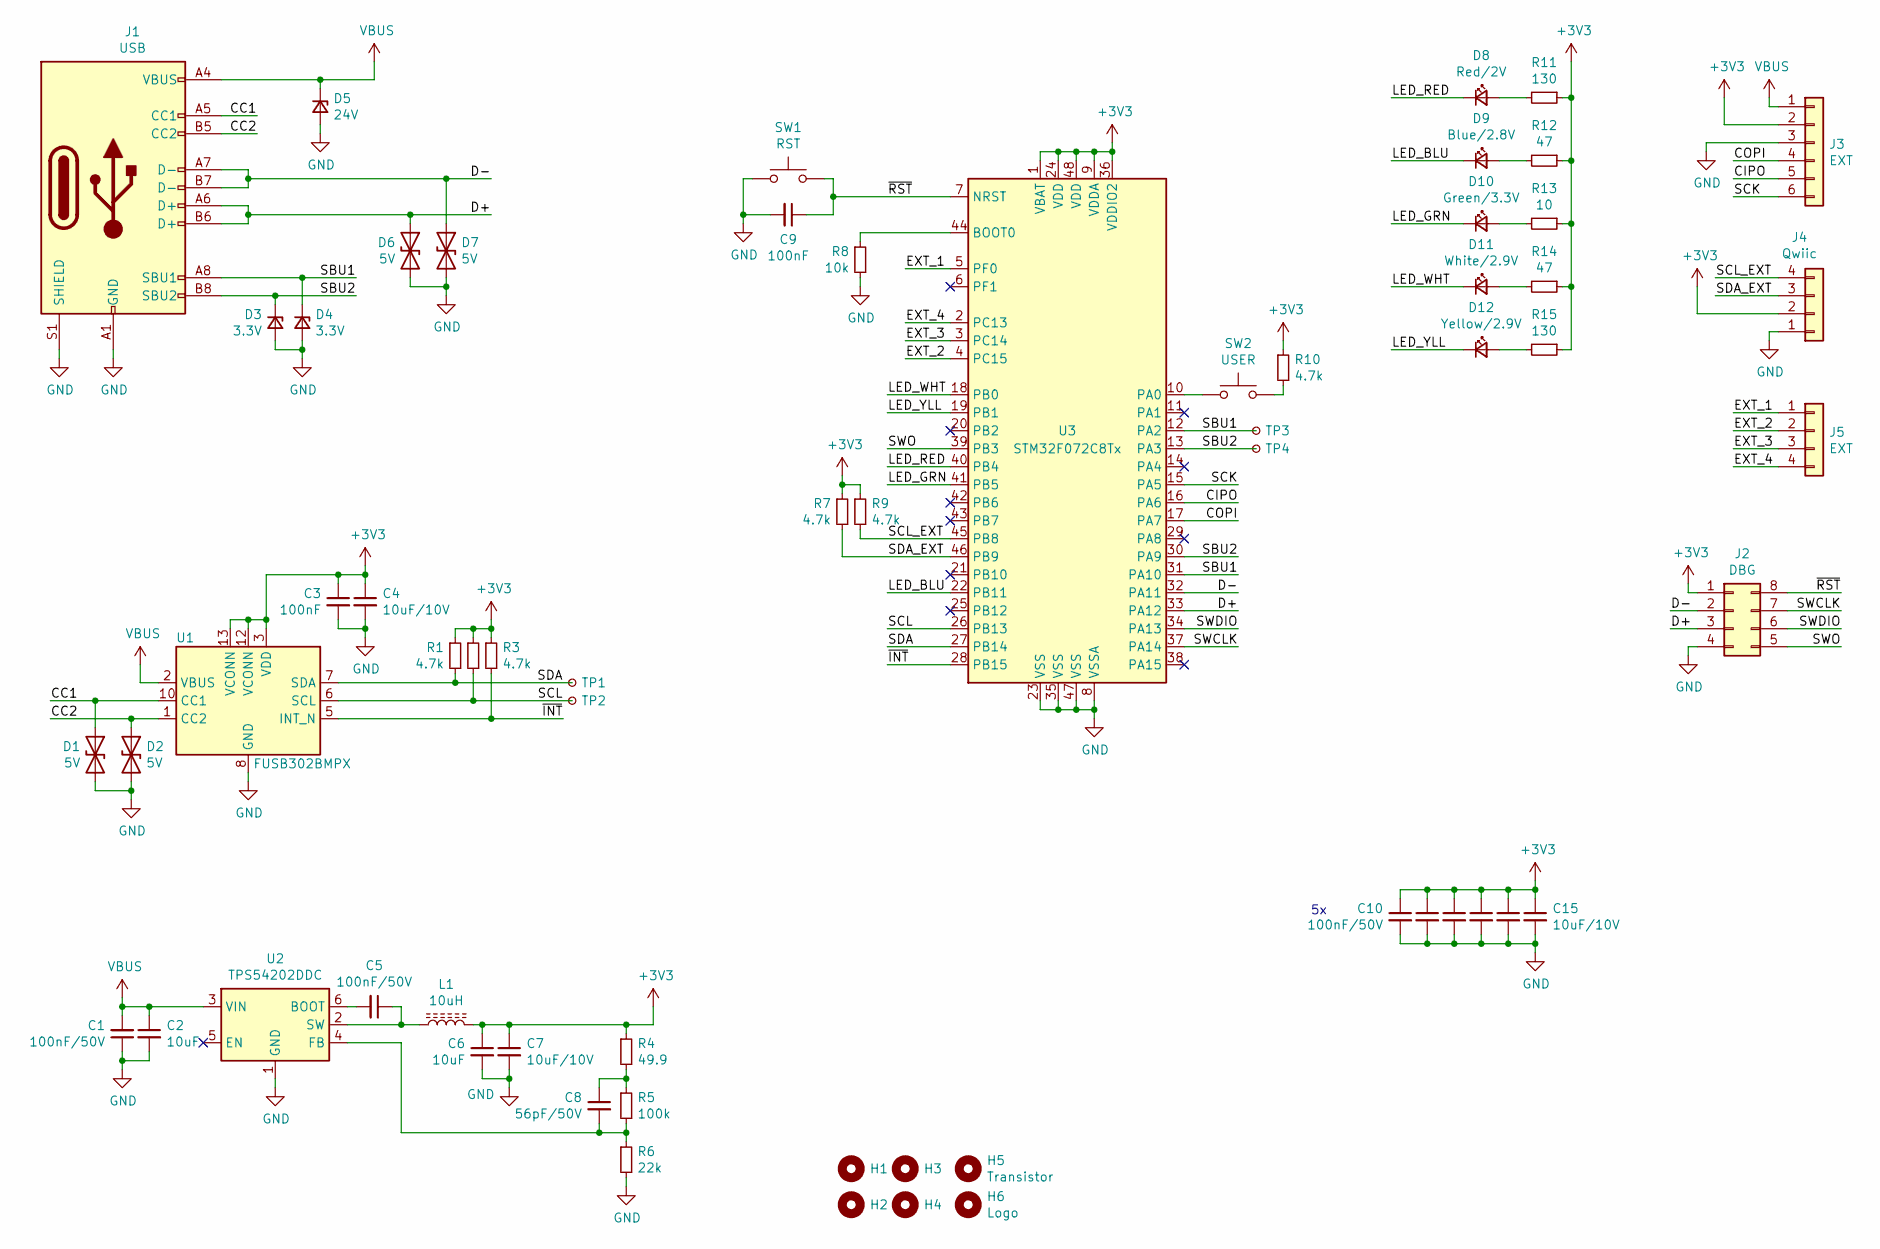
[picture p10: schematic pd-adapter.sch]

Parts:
C1, C5, C10, C11, C12, C13, C14: 100nF/50V; C_0603_1608Metric; MPN CC0603KRX7R9BB104; JLC 0603
C2: 10uF; C_1206_3216Metric; MPN CL31A106KBHNNNE; JLC 1206
C3, C9: 100nF; C_0603_1608Metric; MPN CC0603KRX7R9BB104; JLC 0603
C4, C7, C15: 10uF/10V; C_0603_1608Metric; MPN CL10A106KP8NNNC; JLC 0603
C6: 10uF; C_0603_1608Metric; MPN CL10A106KP8NNNC; JLC 0603
C8: 56pF/50V; C_0603_1608Metric; MPN CL10C560JB8NNNC; JLC 0603
D1, D2, D7: 5V; D_SOD-523; MPN CESD523NC5VB; JLC SOD-523
D3, D4: 3.3V; D_SOD-523; MPN LESD5Z3.3T1G; JLC SOD-523
D5: 24V; D_SOD-323; MPN BZT52C22S; JLC SOD-323
D6: 5V; D_SOD-523; MPN CESD523NC5VB; LCSC C266462
D8: Red/2V; LED_0603_1608Metric_Castellated; MPN KT-0603R; JLC LED_0603
D9: Blue/2.8V; LED_0603_1608Metric_Castellated; MPN 19-217/BHC-ZL1M2RY/3T; JLC LED_0603
D10: Green/3.3V; LED_0603_1608Metric_Castellated; MPN 19-217/GHC-YR1S2/3T; JLC LED_0603
D11: White/2.9V; LED_0603_1608Metric_Castellated; MPN C2290; JLC LED_0603
D12: Yellow/2.9V; LED_0603_1608Metric_Castellated; MPN 19-213/Y2C-CQ2R2L/3T(CY); JLC LED_0603
H1, H2, H3, H4: MountingHole; MountingHole_3.2mm_M3_ISO14580_Pad
H5: Transistor; transistor_10x10mm
H6: Logo; fully_automated_logo_silkscreen
J1: USB; USB_C_Receptacle_XKB_U262-16XN-4BVC11; MPN C167321
J2: DBG; SOIC_clipProgSmall
J3: EXT; PinHeader_1x06_P2.54mm_Vertical
J4: Qwiic; JST_SH_SM04B-SRSS-TB_1x04-1MP_P1.00mm_Horizontal; MPN SM04B-SRSS-TB; LCSC C160404
J5: EXT; PinHeader_1x04_P2.54mm_Vertical
L1: 10uH; L_1210_3225Metric; MPN LQH32CN100K33L; JLC 1210
R1, R2, R3, R7, R9, R10: 4.7k; R_0603_1608Metric; MPN 0603WAF4701T5E; JLC 0603
R4: 49.9; R_0603_1608Metric; MPN 0603WAF499JT5E; JLC 0603
R5: 100k; R_0603_1608Metric; MPN 0603WAF1003T5E; JLC 0603
R6: 22k; R_0603_1608Metric; MPN 0603WAF2202T5E; JLC 0603
R8: 10k; R_0603_1608Metric; MPN 0603WAF1002T5E; JLC 0603
R11, R15: 130; R_0603_1608Metric; MPN 0603WAF499JT5E; JLC 0603
R12, R14: 47; R_0603_1608Metric; MPN 0603WAF470JT5E; JLC 0603
R13: 10; R_0603_1608Metric; MPN 0603WAF100JT5E; JLC 0603
SW1: RST; SW_SPST_PTS636_G; MPN DNP
SW2: USER; SW_SPST_PTS636_G; MPN DNP
TP1: SDA; TestPoint_THTPad_D2.0mm_Drill1.0mm
TP2: SCL; TestPoint_THTPad_D2.0mm_Drill1.0mm
TP3: SBU1; TestPoint_THTPad_D2.0mm_Drill1.0mm
TP4: SBU2; TestPoint_THTPad_D2.0mm_Drill1.0mm
U1: FUSB302BMPX; WQFN-14-1EP_2.5x2.5mm_P0.5mm_EP1.45x1.45mm; MPN FUSB302BMPX; JLC MLP-14_EP_2.5x2.5x0.5P
U2: TPS54202DDC; SOT-23-6; MPN TPS54202DDCR; JLC SOT-23-6L
U3: STM32F072C8Tx; LQFP-48_7x7mm_P0.5mm; MPN STM32F072C8T6; JLC LQFP-48_7.0x7.0x0.5P

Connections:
+3V3: C3.1, C4.1, C6.1, C7.1, C10.1, C11.1, C12.1, C13.1, C14.1, C15.1, J2.1, J3.2, J4.2, L1.2, R1.1, R2.1, R3.1, R4.1, R7.1, R9.1, R10.1, R11.1, R12.1, R13.1, R14.1, R15.1, U1.3 (VDD), U1.4 (VDD), U1.12 (VCONN), U1.13 (VCONN), U3.1 (VBAT), U3.9 (VDDA), U3.24 (VDD), U3.36 (VDDIO2), U3.48 (VDD)
/CC1: D1.1 (A1), J1.A5 (CC1), U1.10 (CC1), U1.11 (CC1)
/CC2: D2.1 (A1), J1.B5 (CC2), U1.1 (CC2), U1.14 (CC2)
/CIPO: J3.5, U3.16 (PA6)
/COPI: J3.4, U3.17 (PA7)
/D+: D6.1 (A1), J1.A6 (D+), J1.B6 (D+), J2.3, U3.33 (PA12)
/D-: D7.1 (A1), J1.A7 (D-), J1.B7 (D-), J2.2, U3.32 (PA11)
/EXT_1: J5.1, U3.5 (PF0)
/EXT_2: J5.2, U3.4 (PC15)
/EXT_3: J5.3, U3.3 (PC14)
/EXT_4: J5.4, U3.2 (PC13)
/LED_BLU: D9.1 (K), U3.22 (PB11)
/LED_GRN: D10.1 (K), U3.41 (PB5)
/LED_RED: D8.1 (K), U3.40 (PB4)
/LED_WHT: D11.1 (K), U3.18 (PB0)
/LED_YLL: D12.1 (K), U3.19 (PB1)
/SBU1: D4.1 (K), J1.A8 (SBU1), TP3.1, U3.12 (PA2), U3.31 (PA10)
/SBU2: D3.1 (K), J1.B8 (SBU2), TP4.1, U3.13 (PA3), U3.30 (PA9)
/SCK: J3.6, U3.15 (PA5)
/SCL: R2.2, TP2.1, U1.6 (SCL), U3.26 (PB13)
/SCL_EXT: J4.4, R9.2, U3.45 (PB8)
/SDA: R1.2, TP1.1, U1.7 (SDA), U3.27 (PB14)
/SDA_EXT: J4.3, R7.2, U3.46 (PB9)
/SWCLK: J2.7, U3.37 (PA14)
/SWDIO: J2.6, U3.34 (PA13)
/SWO: J2.5, U3.39 (PB3)
/~INT: R3.2, U1.5 (INT_N), U3.28 (PB15)
/~RST: C9.1, J2.8, SW1.1, U3.7 (NRST)
GND: C1.1, C2.2, C3.2, C4.2, C6.2, C7.2, C9.2, C10.2, C11.2, C12.2, C13.2, C14.2, C15.2, D1.2 (A2), D2.2 (A2), D3.2 (A), D4.2 (A), D5.2 (A), D6.2 (A2), D7.2 (A2), J1.A1 (GND), J1.A12 (GND), J1.B1 (GND), J1.B12 (GND), J1.S1 (SHIELD), J2.4, J3.3, J4.1, R6.2, R8.2, SW1.2, U1.8 (GND), U1.9 (GND), U1.15 (GND), U2.1 (GND), U3.8 (VSSA), U3.23 (VSS), U3.35 (VSS), U3.47 (VSS)
unnamed: C5.1, L1.1, U2.2 (SW)
unnamed: C5.2, U2.6 (BOOT)
unnamed: C8.1, R4.2, R5.1
unnamed: C8.2, R5.2, R6.1, U2.4 (FB)
unnamed: D8.2 (A), R11.2
unnamed: D9.2 (A), R12.2
unnamed: D10.2 (A), R13.2
unnamed: D11.2 (A), R14.2
unnamed: D12.2 (A), R15.2
unnamed: R8.1, U3.44 (BOOT0)
unnamed: R10.2, SW2.1
unnamed: SW2.2, U3.10 (PA0)
VBUS: C1.2, C2.1, D5.1 (K), J1.A4 (VBUS), J1.A9 (VBUS), J1.B4 (VBUS), J1.B9 (VBUS), J3.1, U1.2 (VBUS), U2.3 (VIN)

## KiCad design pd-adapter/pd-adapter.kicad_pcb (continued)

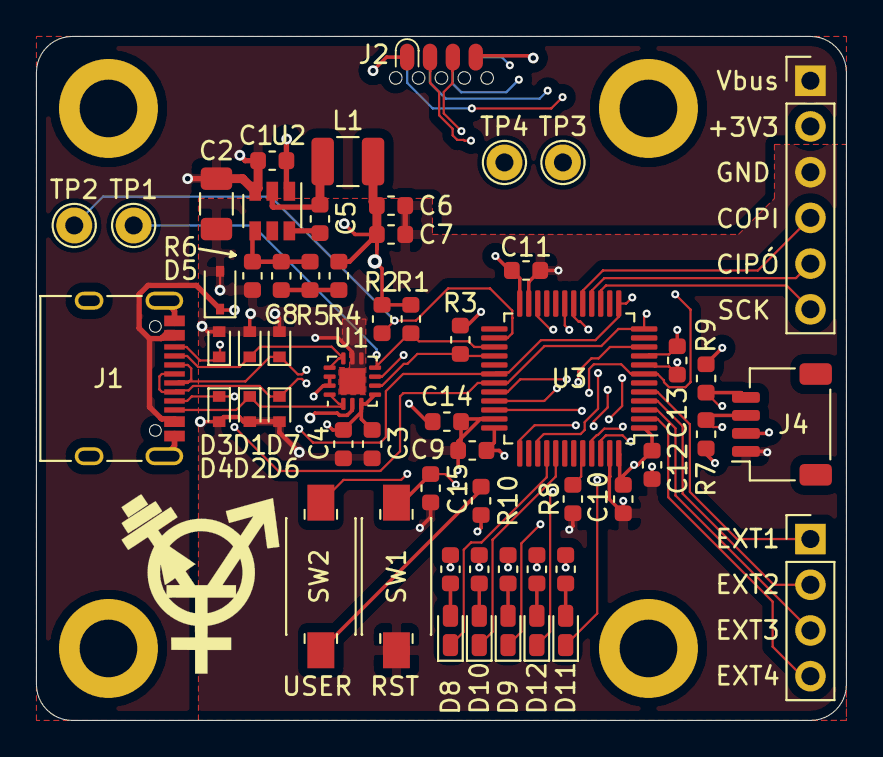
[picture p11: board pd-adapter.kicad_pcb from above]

Board: 4 copper layers, 45.0 x 38.0 mm, 63 parts (1 on the bottom side), 42 nets.

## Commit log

2020-06-21 moar progress
    [ferret.sch]
2020-06-21 almost there
    [ferret.sch]
2020-06-21 more changes
    [ferret.sch]
2020-06-21 Schematic is pretty much finished now
    [ferret.sch]
2020-06-21 some shuffeling
    [ferret.sch]
2020-06-21 Annotate schematic
    [ferret.sch]
2020-06-21 Enable dead battery operation
    [ferret.sch]
2020-06-21 Set to 2S default so that VSYS will always be higher than 4V
    [ferret.sch]
2020-06-21 Add MCU sheet
    [MCU.sch, ferret.sch]
2020-06-22 almost done
    [MCU.sch, ferret.sch]
2020-06-23 Looks good, just needs some more checking
    [MCU.sch, ferret.sch]
2020-06-23 added reverse polarity protection at VIN2
    [ferret.sch]
2020-06-24 Add some footprints to parts
    [MCU.sch, ferret.sch]
2020-06-24 Re-annotated, add more footprints
    [MCU.sch, ferret.sch]
2020-06-26 Some more work
    [MCU.sch, ferret.sch]
2020-06-28 Add PD adapter schematic
    [pd-adapter.kicad_pcb, pd-adapter.sch]
2020-06-29 LED stonks
    [pd-adapter.sch]
2020-06-29 Mounting holes and logos
    [pd-adapter.sch]
2020-06-29 First pass at adapter layout, needs second revision
    [pd-adapter.kicad_pcb, pd-adapter.sch]
2020-06-30 Finished it, one more pair of eyes and it can go into production
    [pd-adapter.kicad_pcb, pd-adapter.sch, pd-adapter_bom.csv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]
2020-07-01 Split up ferret sheets and add some features
    [MCU.sch, control.sch, ferret.sch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]
2020-07-01 I'm pretty happy with it now, will place tomorrow
    [control.sch, ferret.sch, input.sch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]
2020-07-02 Add some part numbers, more changes
    [control.sch, ferret.sch, input.sch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]
2020-07-03 Schematic is done now
    [control.sch, input.sch]
2020-07-03 Start with layout
    [control.sch, ferret.kicad_pcb, input.sch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]
2020-07-04 placed to 50x50mm, started to route
    [control.sch, ferret.kicad_pcb, ferret.sch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]
2020-07-10 partially routed
    [control.sch, ferret.kicad_pcb, input.sch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]
2020-07-12 fully routed but silk is still not done
    [ferret.kicad_pcb, ferret.sch, input.sch]
2020-07-12 Fix silkscreen, still needs some sillyness
    [ferret.kicad_pcb]
2020-07-12 Add initial polecat schematic
    [polecat.kicad_pcb, polecat.sch]
2020-07-12 Add a few more PNs, change D401 to a standard part
    [control.sch, ferret.kicad_pcb, input.sch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]
2020-07-12 added a crystal
    [control.sch, ferret.kicad_pcb]
2020-07-15 finished routing. no silk artwork.
    [control.sch, ferret.kicad_pcb, ferret.sch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]
2020-07-16 Add a few more parts, fix PCB origin problem
    [control.sch, ferret.kicad_pcb, input.sch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]
2020-07-16 added missing JLC/LCSC parts
    [control.sch, ferret.kicad_pcb, input.sch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]
2020-07-16 changed 127k to 120k
    [ferret.kicad_pcb, power.sch]
2020-07-16 It's production ready now. Bottom half is fully assembled by JLC.
    [control.sch, ferret.kicad_pcb]
2020-07-23 updated USB protection IC with package 3D model
    [ferret.kicad_pcb, input.sch]
2020-07-23 added 3D models
    [control.sch, ferret.kicad_pcb, input.sch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]
2020-08-14 added stencil jig
    [jig.3mf, jig.scad]
2020-08-14 added dimensions
    [ferret.kicad_pcb]
2020-08-19 enlarged stencil jig
    [jig.scad]
